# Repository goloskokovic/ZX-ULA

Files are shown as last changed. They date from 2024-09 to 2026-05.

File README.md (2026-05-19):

ULA CPLD Project - Clone of the ZX Spectrum ULA.

This project aims to replace a custom-made component for the 8-bit microcomputer ZX Spectrum manufactured by the English company Sinclair Research.

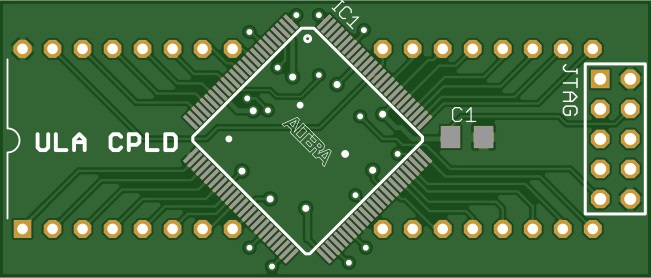
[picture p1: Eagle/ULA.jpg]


Details

All this work was based on the work of Chris Smith [1] and done jointly by the project authors. Thanks to the people from the Brazilian discussion lists "ClubedoTK" [2] and "TK90X" [3] who encouraged and helped in the development of this project.

On the website [4] there is a small diary created by Victor Trucco describing the steps during the development of the project.

The project [5] has two revisions, rev1 and rev2, each in a separate folder. In each revision there is a folder with the PCB design, a folder with the Gerber fabrication files and a folder with the CPLD source code project. The software version used for PCB design was Cadsoft Eagle, and the software used for CPLD design was Altera Quartus version 10.1sp1.

In the "VHDL Version" folder, there is a version of the CPLD code written entirely in VHDL, for both Altera and Xilinx CPLDs. This code was not used in the final ULA CPLD. This is the version used here.

The final product is a small board designed to be inserted directly into the socket of the original integrated circuit, thus replacing the defective component, with the advantage of having a 15kHz analog RGB output for direct use with compatible monitors.

Assembly

Solder the SMD components, obtain an 80-pin turned terminal block, cut it in half for the two 40-pin sides. The CPLD occupies the space of four pins on each side of the turned terminal block, so it is necessary to cut the 4 central pins of each block to make an SMD solder joint at these points.

Place the block in position to find out which pins should be cut, cut with thin cutting pliers to leave it flush with the PCB. Use a 40-pin turned socket and plug the blocks into the socket for aligned soldering. Place the PCB on top of the block and fit the uncut pins into their respective holes and solder them. To solder the 8 cut pins (4 on each side), place the soldering iron tip on one side to heat the PCB and the pin header simultaneously, and apply the solder from the other side. Check with a magnifying glass to ensure successful soldering.

If using the 15kHz RGB output, solder a 90-degree pin header to the PCB, and in revision 2, solder the synchronization jumper. You can choose which type of synchronization will go to the monitor, separate or composite. Depending on the monitor, one type may be better than the other, so it may be necessary to test both types; however, the separate synchronization option has greater compatibility with monitors.

In the Photos folder, there are some photos of the first prototype built.

CPLD Programming

To program the CPLD, a USB Blaster device specific to Altera CPLDs is required. In PCB rev1, the contact points for the programming signals are spread across the PCB, requiring the construction of a "nail bed" or soldering of wires to the points. For rev2, the signals are arranged in a 1x6 connector. The signal names are on the PCB silkscreen. It is necessary to use an external 5V power supply and apply 5V to the VCC pin of the USB Blaster, as it does not power the device but detects if it is powered.

Open the project in Quartus software and go to the programmer. Power the PCB and the USB Blaster and click "Program". If there is a failure in this step, check the connections and check if 5V is going to the USB Blaster. The file needed for programming is called "ULA.pof".

Usage

It is highly recommended to replace the ULA socket on the ZX Spectrum PCB with a machined socket, however, it is possible to use the original. Carefully plug the ULA PCB into the TK socket, pressing slowly to avoid bending any pins. If everything goes well, just turn on the computer and enjoy your new ULA.

Links

[1] http://www.zxdesign.info/thebeginning.shtml [2] http://br.groups.yahoo.com/group/ClubedoTK/ [3] http://br.groups.yahoo.com/group/TK90X/ [4] http://www.victortrucco.com/TK/ULATKCPLD/ULATKCPLD.asp [5] https://github.com/fbelavenuto/tk90x_ula

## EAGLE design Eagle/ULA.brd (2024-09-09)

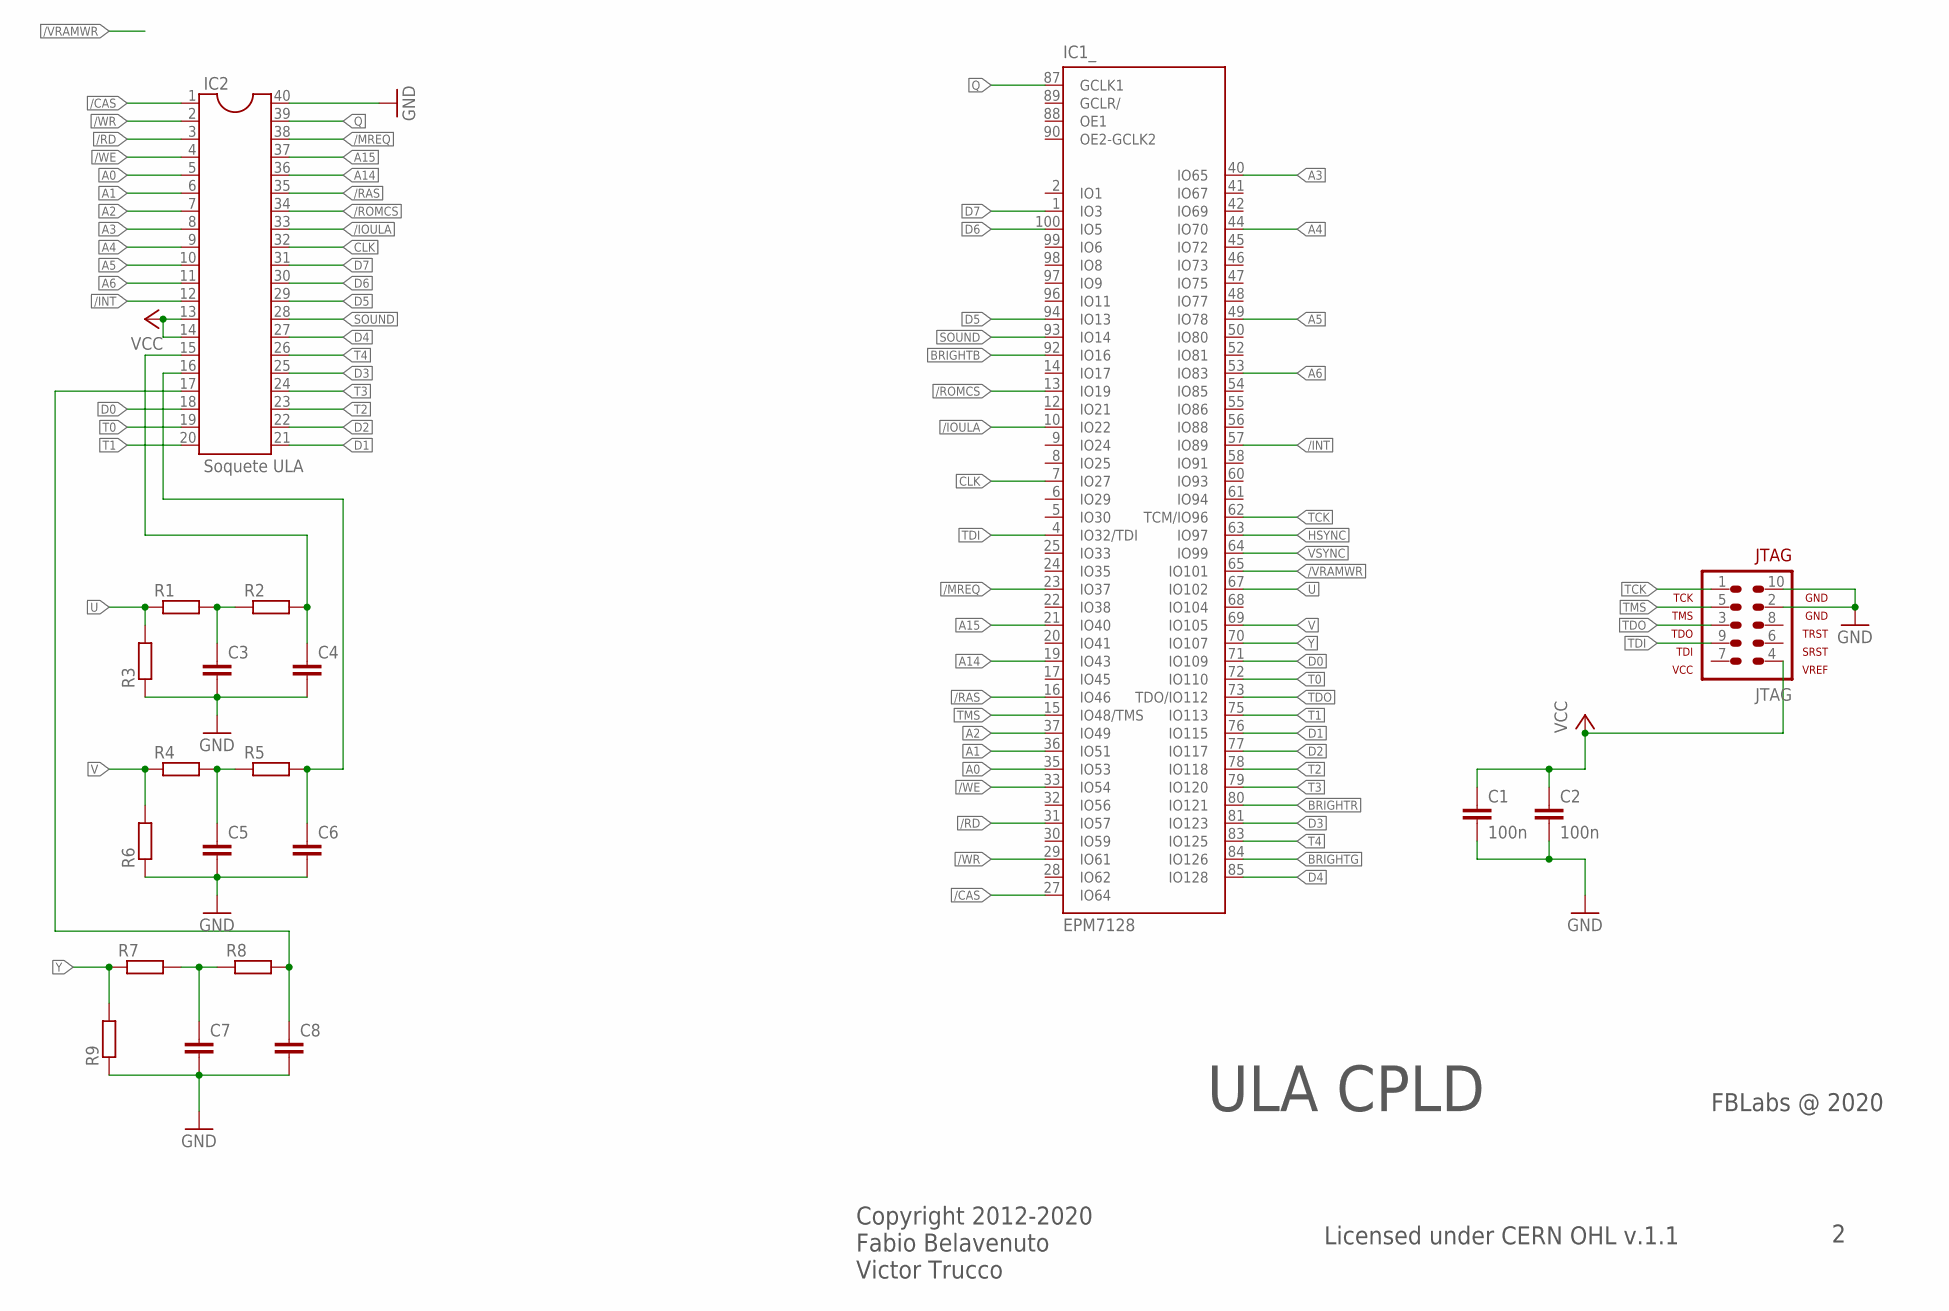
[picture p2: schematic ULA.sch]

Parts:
C1, C2: 100n; C1206
C3, C4, C5, C6, C7, C8: C-EUC0805K; C0805K
IC1: EPM7128; TQFP100
IC2: Soquete ULA; DIL40
JTAG: AVR-JTAG-10
R1, R2, R3, R4, R5, R6, R7, R8, R9: R-EU_M0805; M0805

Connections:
/CAS: IC1.27 (IO64), IC2.1
/INT: IC1.57 (IO89), IC2.12
/IOULA: IC1.10 (IO22), IC2.33
/MREQ: IC1.23 (IO37), IC2.38
/RAS: IC1.16 (IO46), IC2.35
/RD: IC1.31 (IO57), IC2.3
/ROMCS: IC1.13 (IO19), IC2.34
/VRAMWR: IC1.65 (IO101)
/WE: IC1.33 (IO54), IC2.4
/WR: IC1.29 (IO61), IC2.2
A0: IC1.35 (IO53), IC2.5
A1: IC1.36 (IO51), IC2.6
A2: IC1.37 (IO49), IC2.7
A3: IC1.40 (IO65), IC2.8
A4: IC1.44 (IO70), IC2.9
A5: IC1.49 (IO78), IC2.10
A6: IC1.53 (IO83), IC2.11
A14: IC1.19 (IO43), IC2.36
A15: IC1.21 (IO40), IC2.37
BRIGHTB: IC1.92 (IO16)
BRIGHTG: IC1.84 (IO126)
BRIGHTR: IC1.80 (IO121)
CLK: IC1.7 (IO27), IC2.32
D0: IC1.71 (IO109), IC2.18
D1: IC1.76 (IO115), IC2.21
D2: IC1.77 (IO117), IC2.22
D3: IC1.81 (IO123), IC2.25
D4: IC1.85 (IO128), IC2.27
D5: IC1.94 (IO13), IC2.29
D6: IC1.100 (IO5), IC2.30
D7: IC1.1 (IO3), IC2.31
GND: C1.2, C2.2, C3.2, C4.2, C5.2, C6.2, C7.2, C8.2, IC1.11 (GND), IC1.26 (GND), IC1.38 (GND), IC1.43 (GND), IC1.59 (GND), IC1.74 (GND), IC1.86 (GND), IC1.95 (GND), IC2.40, JTAG.2, JTAG.10, R3.1, R6.1, R9.1
HSYNC: IC1.63 (IO97)
unnamed: C5.1, R4.2, R5.1
unnamed: C3.1, R1.2, R2.1
unnamed: C4.1, IC2.15, R2.2
unnamed: C6.1, IC2.16, R5.2
unnamed: C7.1, R7.2, R8.1
unnamed: C8.1, IC2.17, R8.2
Q: IC1.87 (GCLK1), IC2.39
SOUND: IC1.93 (IO14), IC2.28
T0: IC1.72 (IO110), IC2.19
T1: IC1.75 (IO113), IC2.20
T2: IC1.78 (IO118), IC2.23
T3: IC1.79 (IO120), IC2.24
T4: IC1.83 (IO125), IC2.26
TCK: IC1.62 (TCM/IO96), JTAG.1
TDI: IC1.4 (IO32/TDI), JTAG.9
TDO: IC1.73 (TDO/IO112), JTAG.3
TMS: IC1.15 (IO48/TMS), JTAG.5
U: IC1.67 (IO102), R1.1, R3.2
V: IC1.69 (IO105), R4.1, R6.2
VCC: C1.1, C2.1, IC1.39 (VCC), IC1.91 (VCC), IC2.13, IC2.14, JTAG.4
VCCIO: IC1.3 (VCCIO), IC1.18 (VCCIO), IC1.34 (VCCIO), IC1.51 (VCCIO), IC1.66 (VCCIO), IC1.82 (VCCIO)
VSYNC: IC1.64 (IO99)
Y: IC1.70 (IO107), R7.1, R9.2

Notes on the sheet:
ULA CPLD
Licensed under CERN OHL v.1.1
Copyright 2012-2020 Fabio Belavenuto Victor Trucco
FBLabs @ 2020

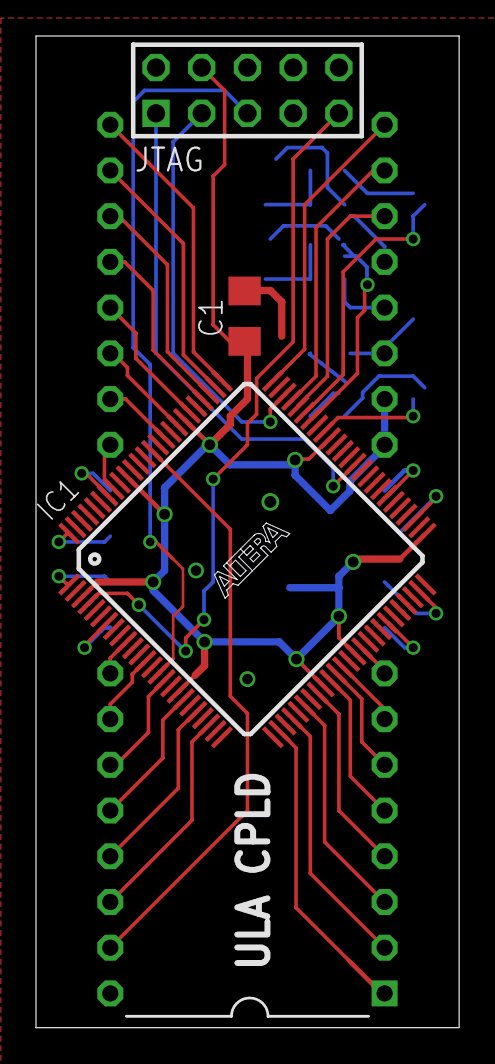
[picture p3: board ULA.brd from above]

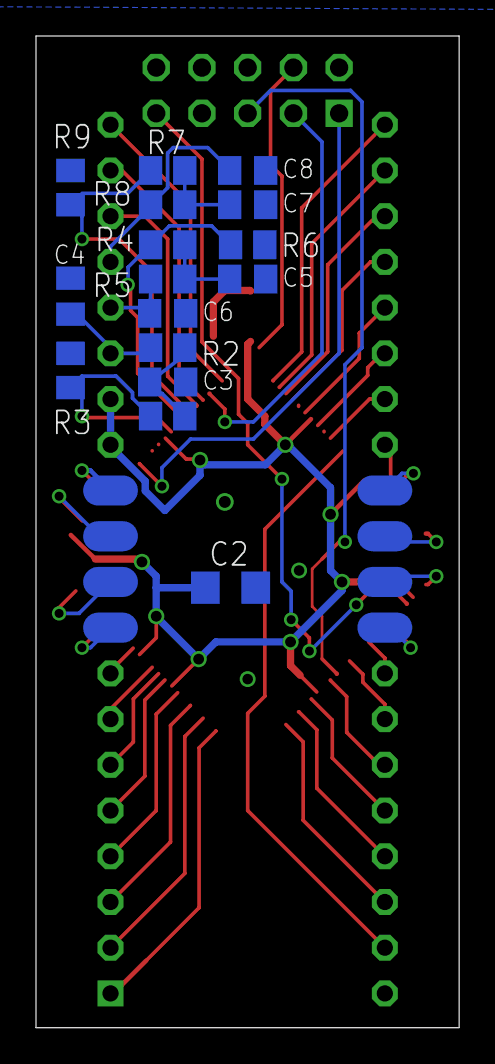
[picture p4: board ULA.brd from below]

Board: 2 copper layers, 23.5 x 55.1 mm, 20 parts (16 on the bottom side), 50 nets.

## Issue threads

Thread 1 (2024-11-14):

vhdl code not working

Johnapteka, 2024-11-14:
Hi,
Your code is not working.
line 561: Operator <DIVIDE> must have constant operands or first operand must be power of 2

goloskokovic, 2024-11-15:
Hi,
what are you using to compile vhdl?

Johnapteka, 2024-11-15:
Hi,
ISE 14.7

goloskokovic, 2024-11-15:
try Quartus II 13.0.1
https://github.com/goloskokovic/ZX-ULA/blob/main/synt/Altera%20EPM7128/ULA_CPLD.qpf#L20

didn't test Xilinx, only Altera. be aware this code needs more powerful CPLD to run analog YUV output

goloskokovic, 2024-11-15:
it might just need optimization for the YUV analog output like using 16bit numbers. don't know how ALU in Altera MAX 7000 works.

To generate analog signal:
1. you can use PWM included in the source with passive filters:
https://www.allegromicro.com/en/insights-and-innovations/technical-documents/hall-effect-sensor-ic-publications/method-for-converting-a-pwm-output-to-an-analog-outpu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
2. another way is to use 3x DAC like this one:
https://www.analog.com/en/products/max5101.html

goloskokovic, 2024-11-21:
can you try to compile?
YUV has been optimized for PWM output. I need to add passive filters on the board in Eagle.

Johnapteka, 2024-12-24:
Compiled, but no signal at output. I think this code doesn´t work.

goloskokovic, 2024-12-25:
How do you test the code?

Johnapteka, 2024-12-25:
In a test board with the Altera.

goloskokovic, 2024-12-26:
I am certain YUV output is not right as you need at least 8bit number precision for PWM to work.
I need to optimise YUV code to fit in 128 macrocells of MAX 7000:
https://www.synthworks.com/papers/vhdl_math_tricks_mapld_2003.pdf

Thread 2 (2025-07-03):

RC values on the schematic

robertgida, 2025-07-03:
Hello,
what are the values of the R and C on the YUV lines?  Is that part not finished yet?
Except from the analog video output, is the code working as an ULA in a real machine?
Thanks.

robertgida, 2025-07-04:
Actually, is the cpld handles well the 14MHz OSC from the ZX? That sign is a pathetic thing imho. That's why every ula replacement has own clock yource. Try with an external 14MHz. :)

robertgida, 2025-07-04:
Actually, I made a try with a cpld panel. Nothing on the screen, yes, analog output not working, I know.
Ok, I skipped this, and make R,G,B and Csync signs on 4 pins, and made a makeshift Composite video with AD724, which is worked before on an other project. No screen at all. OK, I skipped the OSC signal coming from the motherboard (that's a terrible signal imho) and used a 14MHz oscillator with 74HC04 and some passsive elements. Finally, nice 14MHz going onto the cpld, and  got some picture, but running badly.  As I check, there is a white screen. I grabbed some ZX diag cartridge, and yes, the screen is changing, I see something, I can say, the machine is doing somethin, working, but again, the screen is terribly out of sync.

OSC:
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
ula and top vhd I made some mod, but I'm sure, this is not good in this way.

[top_ula_vhd.zip](https://github.com/user-attachments/files/21069845/top_ula_vhd.zip)

robertgida, 2025-07-05:
Yeah, I know that, already tinkered with that, tried to port to ZXSP years ago, but without success. Without much knowledge then, I admit. Thx for the book, btw.
Imho, let's focus on the core itself, even with rgb video output and later if all ok, do an external yuv conversion.

goloskokovic, 2025-07-05:
sync related I only changed Burstgate value from the book pg. 169. So there might be more values to update.

I 've spent 99% of the time on calculating YUV, pg. 158

robertgida, 2025-07-05:
Check this out. It seems, can be useful with infos.
https://github.com/c0pperdragon/ZX-Spectrum-Component-Video

robertgida, 2025-07-07:
I'll check later. I'm on vacation btw. :)

On Mon, Jul 7, 2025 at 11:24 AM goloskokovic ***@***.***>
wrote:

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

robertgida, 2025-07-19:
https://www.victortrucco.com/TK/ULATKCPLD/ULATKCPLD
This is the original (not the github site), translate it with google.

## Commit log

2024-09-09 added filters for PWM
    [ULA.brd, ULA.sch]
2024-09-09 PWM DAC
    https://github.com/rcmschiavi/PWM-in-VHDL/blob/master/PWM.vhd
2024-09-09 CPLD pinout update
    [ULA.brd, ULA.sch]
2024-09-27 YUV PWM
2025-11-04 Initialize README with project details and instructions
    Added detailed project description, assembly instructions, CPLD programming guide, and usage recommendations.
